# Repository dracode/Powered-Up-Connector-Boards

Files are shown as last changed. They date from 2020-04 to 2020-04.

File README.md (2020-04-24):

# Powered-Up-Connector-Boards
This repository contains the circuit board layouts I created to use the Powered Up (aka WeDo 2.0) cables and sockets that I found on AliExpress.

I used these connectors, found on a shop at <A HREF="https://www.aliexpress.com/item/33057514281.html">AliExpress</A>, to make my boards.
<TABLE>
  <TR><TD><B>Female</B></TD><TD><B>Male</B></TD></TR>
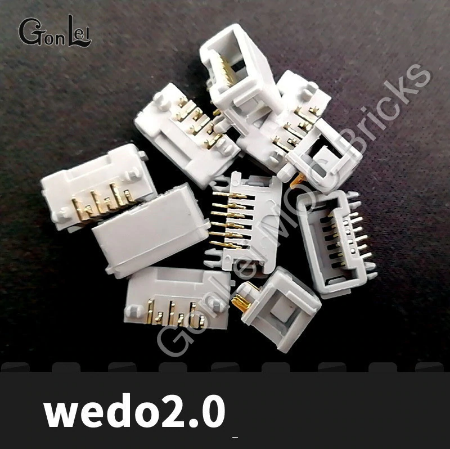
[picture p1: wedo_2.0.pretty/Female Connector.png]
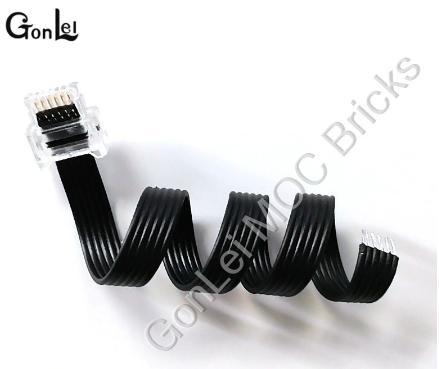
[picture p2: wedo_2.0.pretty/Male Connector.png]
  <TR><TD></TD><TD></TR>
</TABLE>
The male cable will work with a standard 1.27mm pitch pin header.  I created a KiCad part/footprint for the female connector in the "wedo_2.0.lib" and "wedo_2.0.pretty" library.<P>
The female connector has two locating pins on the bottom that will snap in place into the board.  The "neck" on these pins is only approximately 1mm long, so ensure your board is thinner than that if you want the connector to snap into place properly.  I used 0.8mm thickness PCB from <A HREF="https://oshpark.com">OSHPark.com</A> and it worked well.<P>
<P>
Boards I have designed so far:<P>
<TABLE>
<TR><TH>OSHPark Link</TH><TH>Render</TH></TR>
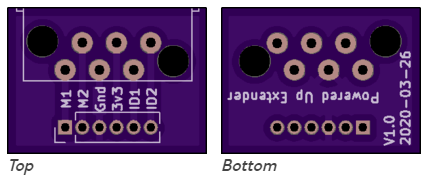
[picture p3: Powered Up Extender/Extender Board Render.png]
<TR><TD><A HREF="https://oshpark.com/shared_projects/C05HhJQx">Powered Up Extender</A></TD><TD></TD></TR>
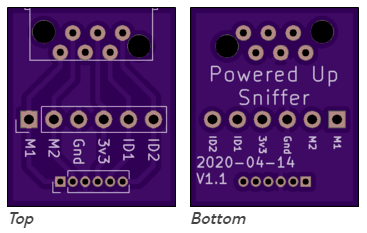
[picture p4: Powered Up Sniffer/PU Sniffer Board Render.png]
<TR><TD><A HREF="https://oshpark.com/shared_projects/9tZOPjXH">Powered Up Extender + 0.1&quot; Pin Headers</A></TD><TD></TD></TR>
<TR><TD><A HREF="https://oshpark.com/shared_projects/ryhlzi0H">Powered Up Train Motor Splitter</A></TD><TD></TD></TR>
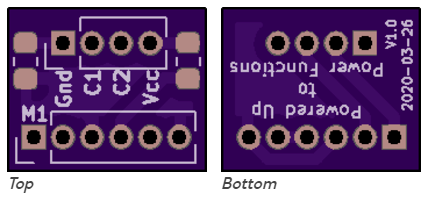
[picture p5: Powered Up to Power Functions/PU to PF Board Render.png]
<TR><TD><A HREF="https://oshpark.com/shared_projects/m9qytbsl">Powered Up to Power Functions Adapter</A></TD><TD></TD></TR>
</TABLE>

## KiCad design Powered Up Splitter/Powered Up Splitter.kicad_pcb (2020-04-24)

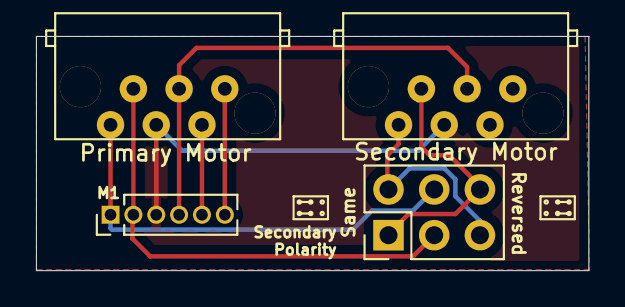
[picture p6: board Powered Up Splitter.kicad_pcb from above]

Board: 2 copper layers, 30.7 x 13.0 mm, 4 parts (0 on the bottom side), 8 nets.

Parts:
J1, J2: FemaleConnector; WeDo 2.0 Female Socket
J3: Conn_01x06; PinHeader_1x06_P1.27mm_Vertical
J4: Conn_02x03_Row_Letter_First; PinHeader_2x03_P2.54mm_Vertical

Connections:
/3V3: J1.4, J2.4, J3.4
/GND: J1.3, J2.3, J3.3
/M1: J1.1, J3.1, J4.4
/M2: J1.2, J3.2, J4.3
unnamed: J1.5, J3.5
unnamed: J1.6, J3.6
unnamed: J2.1, J4.2, J4.5
unnamed: J2.2, J4.1, J4.6

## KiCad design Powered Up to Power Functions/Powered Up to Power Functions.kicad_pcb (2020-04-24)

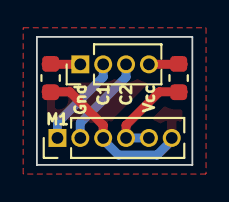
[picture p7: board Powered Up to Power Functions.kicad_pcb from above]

Board: 2 copper layers, 8.6 x 7.1 mm, 4 parts (0 on the bottom side), 6 nets.

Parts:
J1: Conn_01x04; PinHeader_1x04_P1.27mm_Vertical
J3: Conn_01x06; PinHeader_1x06_P1.27mm_Vertical
R1, R2: R_Small_US; R_0603_1608Metric

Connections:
/3V3: J3.4, J3.5, R1.2
/GND: J3.3, J3.6, R2.2
/M1: J1.2, J3.1
/M2: J1.3, J3.2
unnamed: J1.1, R2.1
unnamed: J1.4, R1.1

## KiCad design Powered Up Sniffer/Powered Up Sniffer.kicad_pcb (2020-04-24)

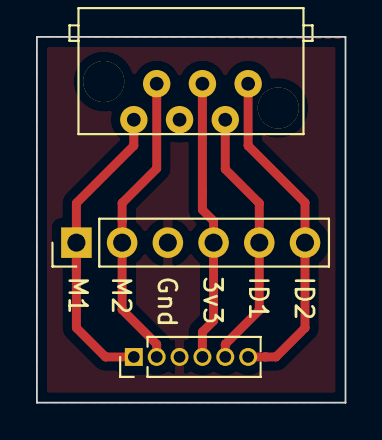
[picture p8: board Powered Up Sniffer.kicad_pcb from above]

Board: 2 copper layers, 17.1 x 20.3 mm, 3 parts (0 on the bottom side), 6 nets.

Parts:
J1: FemaleConnector; WeDo 2.0 Female Socket
J2: Conn_01x06; PinHeader_1x06_P2.54mm_Vertical
J3: Conn_01x06; PinHeader_1x06_P1.27mm_Vertical

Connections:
/3V3: J1.4, J2.4, J3.4
/GND: J1.3, J2.3, J3.3
/M1: J1.1, J2.1, J3.1
/M2: J1.2, J2.2, J3.2
unnamed: J1.5, J2.5, J3.5
unnamed: J1.6, J2.6, J3.6

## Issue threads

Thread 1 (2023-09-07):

Are these tested?

iragm, 2023-09-07:
Your Powered Up Train Motor Splitter looks insanely useful.  On Eurobricks, you mentioned that it was designed but not tested - has it been tested now?

iragm, 2023-09-25:
The answer is yes, the splitter works.  The only issue is that the holes for the wire (crystal connector end) are too small, not really an issue as the wire can be soldered to the top of the board instead.

Closed 2023-09-25.
